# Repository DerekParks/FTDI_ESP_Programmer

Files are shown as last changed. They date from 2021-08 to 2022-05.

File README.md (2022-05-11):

# A FTDI Breakout with auto reset

## Motivation

Around 2008-ish Sparkfun started selling their [FTDI basic breakout](https://www.sparkfun.com/products/retired/9115). 
These were great! And really helped me move beyond having a full Arduino Uno inside of every project.

Fast forward to today. ESP's are king! But we are in a similar situation where [most dev boards](https://components101.com/development-boards/nodemcu-esp8266-pinout-features-and-datasheet) include a built in USB-to-TTL chip.
At least now, we are using FTDI clones that are cheaper. But I still don't want to include extra hardware just for programming in every project! 

For years I have used the [3.3v version of Sparkfun's FTDI breakout](https://www.sparkfun.com/products/9873) for programming ESP's. 
And for an equal amount of years, I've been annoyed that auto-reset doesn't work like on the all-in-one dev boards.

I will freely admit that support for OTA updates has made this less of an annoyance. But when I am working out bugs, I find iterating with a physical programmer faster.

So at some point during the pandemic, I setout to figure out how [the auto-reset feature on ESP's works](https://hallard.me/esp8266-autoreset/) and to make my own FTDI programmer.

## The Programmer

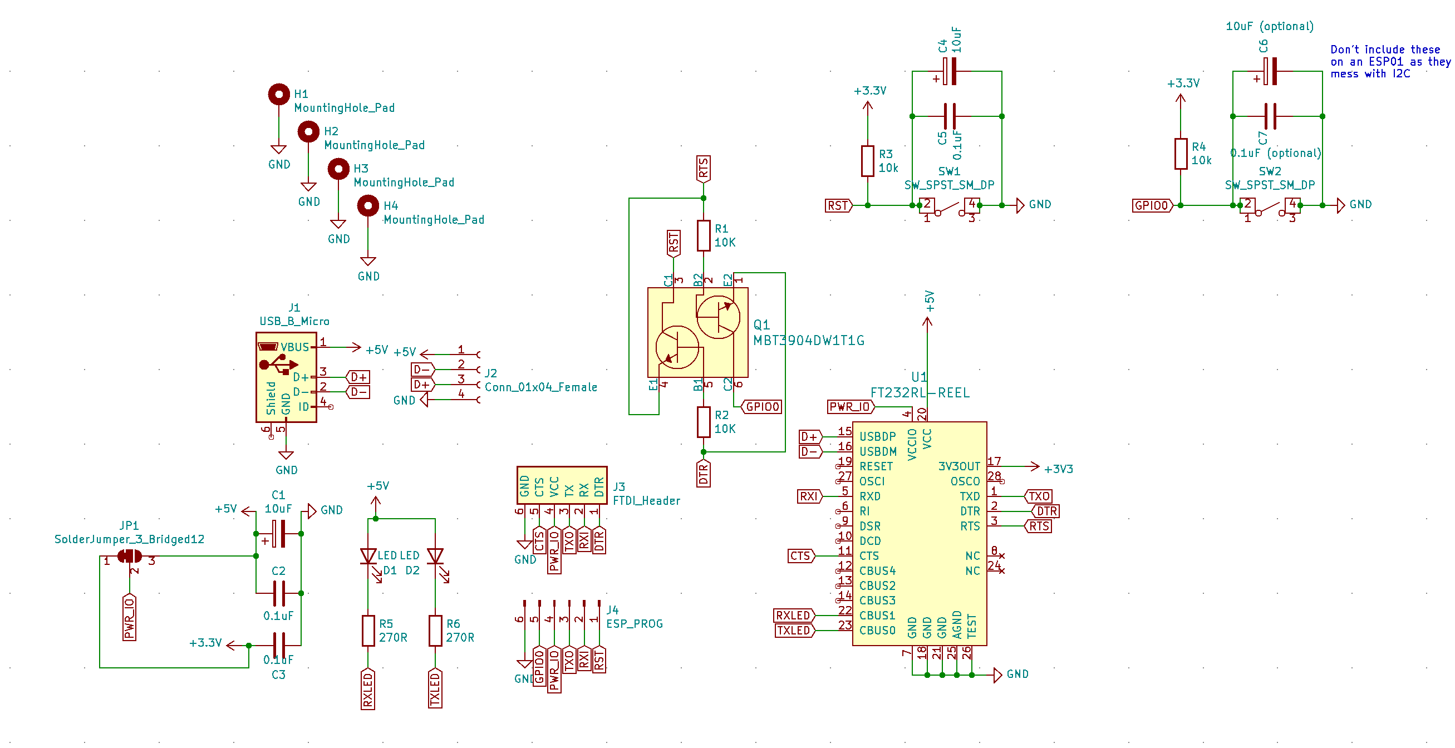
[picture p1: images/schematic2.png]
Schematic


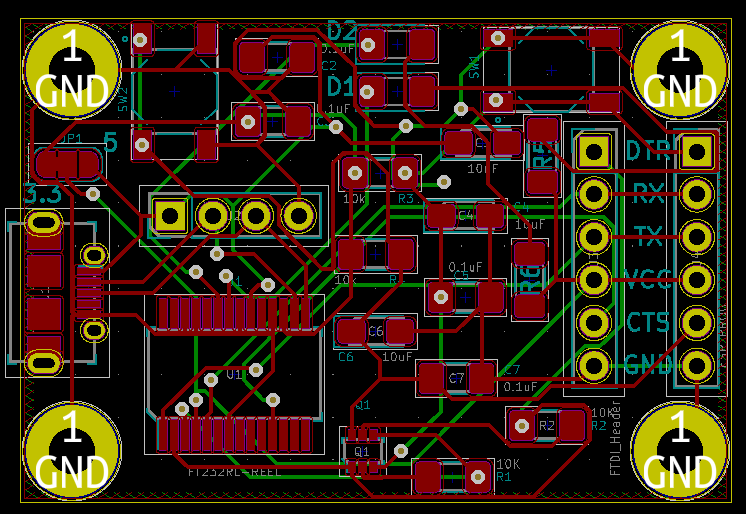
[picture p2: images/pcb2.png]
PCB


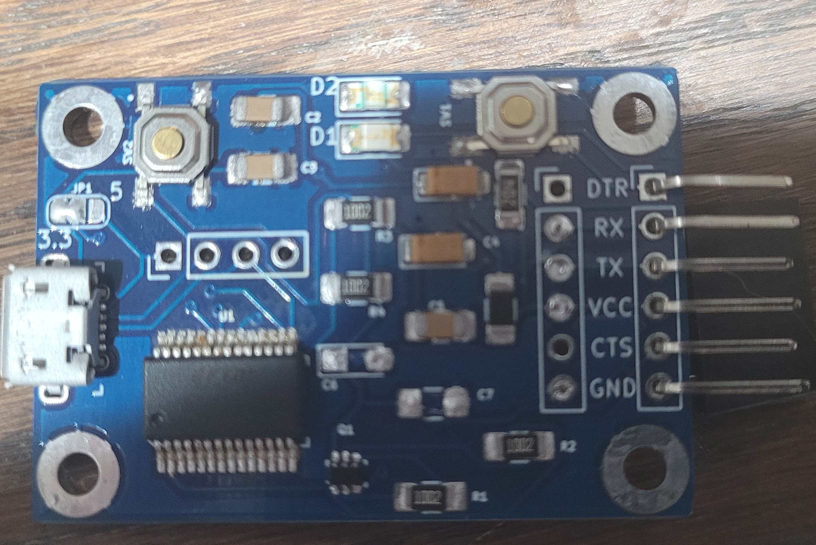
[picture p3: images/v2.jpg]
V1 programmer V1 where I forgot to add current limiting resistors to the status LED's, D'oh!

("V1 where I forgot to add current limiting resistors to the status LED's, D'oh!")

There are also physical tactical flash and reset buttons in case for some reason my amazing auto-reset circuit fails. 

## New standard pinout?

Do I even need to link the standards xkcd[?](https://xkcd.com/927/) Yes, I am proposing a new standard pinout.

| Old Pinouts | My Pinout |
| --- | --- |
| DTR | RST |
| RX | RX |
| TX | TX |
| VCC | VCC |
| CTS | GPIO0 |
| GND | GND |

As you can see I've replaced DTR and CTS with RST and GPIO0, respectively. This board does have the original FTDI standard pins broken out, just-in-case, but so far I haven't ever had cause to use them.

## 3.3 or 5?

There is a solder jumper on the board to switch between 3.3v and 5v. It is set to 3.3v by default.

## C6 & C7

The decoupling, C6 & C7 should be removed if using an ESP01 and I2C.

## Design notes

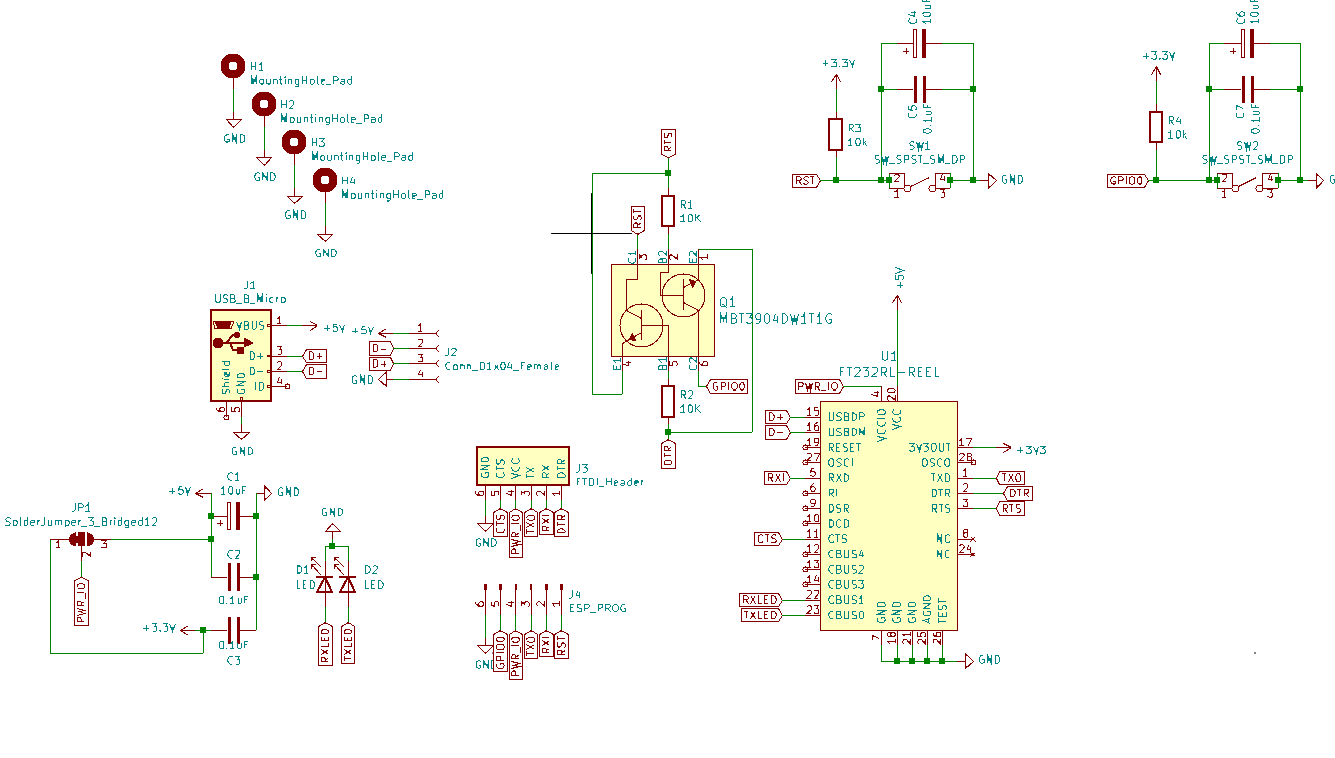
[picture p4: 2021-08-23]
images/schematic.png

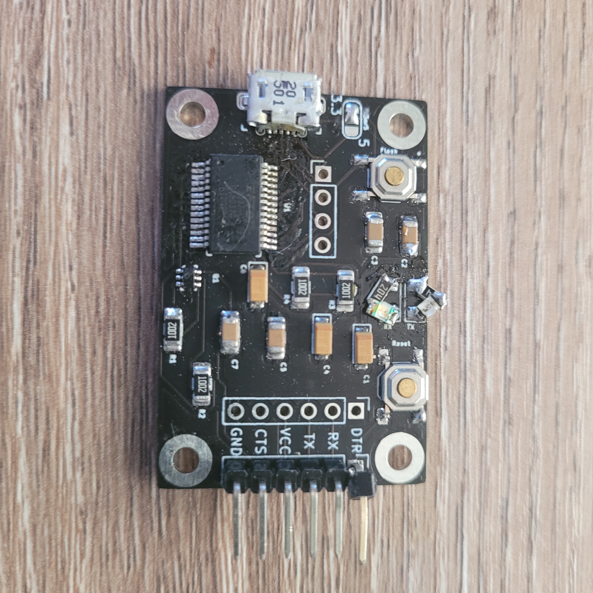
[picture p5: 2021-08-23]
images/v1.jpg

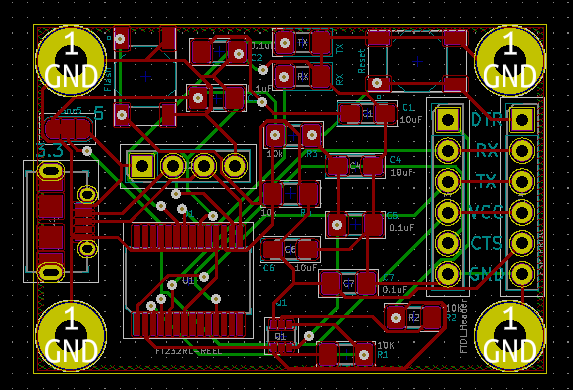
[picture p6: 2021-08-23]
images/pcb.png

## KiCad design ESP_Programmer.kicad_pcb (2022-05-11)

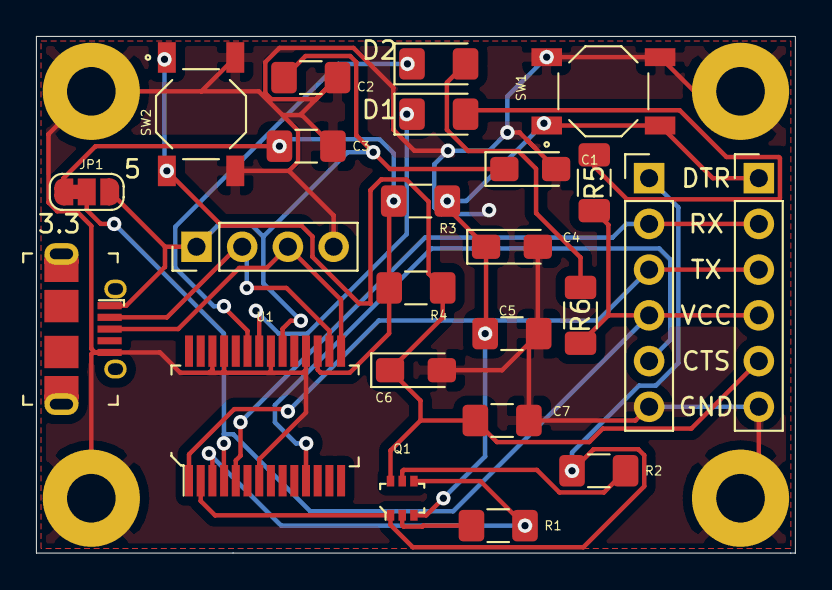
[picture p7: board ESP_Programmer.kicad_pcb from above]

Board: 2 copper layers, 42.2 x 28.7 mm, 28 parts (0 on the bottom side), 19 nets.

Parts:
C1, C4, C6: 10uF; CP_EIA-3216-18_Kemet-A_Pad1.58x1.35mm_HandSolder
C2, C3, C5, C7: 0.1uF; C_1206_3216Metric_Pad1.42x1.75mm_HandSolder
D1, D2: LED; LED_1206_3216Metric_Pad1.42x1.75mm_HandSolder
H1, H2, H3, H4: MountingHole_Pad; MountingHole_2.7mm_M2.5_Pad
J1: USB_B_Micro; USB_Micro_AB_Female_0475890001
J2: Conn_01x04_Female; PinHeader_1x04_P2.54mm_Vertical
J3: FTDI_Header
J4: ESP_PROG; PinHeader_1x06_P2.54mm_Vertical
JP1: SolderJumper_3_Bridged12; SolderJumper-3_P1.3mm_Bridged12_RoundedPad1.0x1.5mm_NumberL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
Q1: MBT3904DW1T1G; SOT-363
R1, R2: 10K; R_1206_3216Metric_Pad1.42x1.75mm_HandSolder
R3, R4: 10k; R_1206_3216Metric_Pad1.42x1.75mm_HandSolder
R5, R6: 270; R_1206_3216Metric_Pad1.30x1.75mm_HandSolder
SW1, SW2: SW_SPST_SM_DP; E-Switch-TL3342F160QG-0
U1: FT232RL-REEL; SSOP-28_W5.30mm

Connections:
+3V3: C3.1, JP1.1, R3.1, R4.1, U1.17
+5V: C1.1, C2.2, J1.1, J2.1, JP1.3, U1.20
CTS: J3.5, U1.11
D+: J1.3, J2.3, U1.15
D-: J1.2, J2.2, U1.16
DTR: J3.1, Q1.1, R2.2, U1.2
GND: C1.2, C2.1, C3.2, C4.2, C5.2, C6.2, C7.2, H1.1, H2.1, H3.1, H4.1, J1.5, J2.4, J3.6, J4.6, SW1.3, SW1.4, SW2.3, SW2.4, U1.7, U1.18, U1.21, U1.25, U1.26
GPIO0: C6.1, C7.1, J4.5, Q1.6, R4.2, SW2.1, SW2.2
unnamed: D1.2, R5.2
unnamed: D2.2, R6.2
unnamed: Q1.2, R1.2
unnamed: Q1.5, R2.1
PWR_IO: J3.4, J4.4, JP1.2, R5.1, R6.1, U1.4
RST: C4.1, C5.1, J4.1, Q1.3, R3.2, SW1.1, SW1.2
RTS: Q1.4, R1.1, U1.3
RXI: J3.2, J4.2, U1.5
RXLED: D1.1, U1.22
TXLED: D2.1, U1.23
TXO: J3.3, J4.3, U1.1

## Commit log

2021-05-14 Inital commit
    [ESP_Programmer.kicad_pcb, ESP_Programmer.sch]
2021-08-21 Added readme
    [ESP_Programmer.sch]
2021-08-23 Add images
    [ESP_Programmer.sch]
2022-05-11 V2 led's and notes about C6 & C7
    [ESP_Programmer-CmtUser.gbr, ESP_Programmer-CuBottom.gbr, ESP_Programmer-CuTop.gbr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]
2022-05-11 readmed updates
    [ESP_Programmer.kicad_pcb]
